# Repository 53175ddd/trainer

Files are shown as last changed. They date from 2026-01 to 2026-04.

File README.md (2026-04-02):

# trainer でできること

Arduino を使ったプログラミング学習用の教材です．段階を踏んで様々なことを学ぶことができるよう開発を進めています．

## 本リポジトリで管理されているもの

- 専用の開発ボード
  - `./boards/`
- 各種サンプルコード
  - `./samples/`
- 各種ドキュメント（Web ページとして公開）
  - `./docs/`
- 関連リンク

## ハードウェア

実習用に，秋月電子で購入できる RP2040 搭載のマイコンボード「AE-RP2040」を使用するハードウェア「trainer-pico」を用意しています．

基板イメージ：<https://kicanvas.org/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>

// 基板が出来上がったら Booth の購入リンクを追加する

## ドキュメント

// ある程度開発が進んでから整備する  
// `./docs/` 以下に配置し GitHub Pages で公開の上，そのリンクをここに貼る

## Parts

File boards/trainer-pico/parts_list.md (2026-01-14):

# trainer-pico 部品表

| 部品番号 | 部品名 | 型番等 | リンク | 備考 |
|:----|:----|:----|:----|:----|
| C1 | コンデンサ | Rubycon 50PX100MEFC8X11.5 | [117905](<https://akizukidenshi.com/catalog/g/g117905/>) | 100uF 50V |
| C2 | コンデンサ | Rubycon 50PX100MEFC8X11.5 | [117905](<https://akizukidenshi.com/catalog/g/g117905/>) | C1 と同じ |
| C3 | コンデンサ | muRata GCM21BR71H224KA37L | [C161262](<https://www.lcsc.com/product-detail/C161262.html>) | PCBA<sup>[1]</sup> |
| C4 | コンデンサ | muRata GCM21BR71H224KA37L | [C161262](<https://www.lcsc.com/product-detail/C161262.html>) | PCBA |
| C5 | コンデンサ | muRata GRM188R71H104KA93D | [C77055](<https://www.lcsc.com/product-detail/C77055.html>) | PCBA |
| C6 | コンデンサ | muRata GRM188R71H104KA93D | [C77055](<https://www.lcsc.com/product-detail/C77055.html>) | PCBA |
| C7 | コンデンサ | Rubycon 25MH747MEFC6.3X7 | [110596](<https://akizukidenshi.com/catalog/g/g110596/>) | 47uF 25V |
| C8 | コンデンサ | Rubycon 25MH747MEFC6.3X7 | [110596](<https://akizukidenshi.com/catalog/g/g110596/>) | C2 と同じ |
| C9 | コンデンサ | muRata GRM31CR61H106KA12L | [C77092](<https://www.lcsc.com/product-detail/C77092.html>) | PCBA |
| D1 | ダイオード | DIODES 1N4148W-7-F | [C83528](<https://www.lcsc.com/product-detail/C83528.html>) | PCBA |
| D2 | ダイオード | DIODES 1N4148W-7-F | [C83528](<https://www.lcsc.com/product-detail/C83528.html>) | D1 と同じ |
| D3 | ダイオード | DIODES 1N4148W-7-F | [C83528](<https://www.lcsc.com/product-detail/C83528.html>) | D1 と同じ |
| J1 | ピンヘッダ | PH-1x40SG | [100167](<https://akizukidenshi.com/catalog/g/g100167/>) | 必要な分だけ折り取って使用 |
| J2 | ピンヘッダ | PH-1x40SG | [100167](<https://akizukidenshi.com/catalog/g/g100167/>) | 必要な分だけ折り取って使用 |
| J3 | ピンヘッダ | PH-1x40SG | [100167](<https://akizukidenshi.com/catalog/g/g100167/>) | 必要な分だけ折り取って使用 |
| J4 | ピンヘッダ | PH-1x40SG | [100167](<https://akizukidenshi.com/catalog/g/g100167/>) | 必要な分だけ折り取って使用 |
| J5 | ピンヘッダ | PH-1x40SG | [100167](<https://akizukidenshi.com/catalog/g/g100167/>) | 必要な分だけ折り取って使用 |
| J6 | ピンソケット | FHU-1x42SG | [105779](<https://akizukidenshi.com/catalog/g/g105779/>) | 必要な分だけ折り取って使用 |
| J7 | ピンソケット | FHU-1x42SG | [105779](<https://akizukidenshi.com/catalog/g/g105779/>) | 必要な分だけ折り取って使用 |
| J8 | ピンソケット | FHU-1x42SG | [105779](<https://akizukidenshi.com/catalog/g/g105779/>) | 必要な分だけ折り取って使用 |
| J9 | ピンソケット | FHU-1x42SG | [105779](<https://akizukidenshi.com/catalog/g/g105779/>) | 必要な分だけ折り取って使用 |
| J10 | ピンソケット | FHU-1x42SG | [105779](<https://akizukidenshi.com/catalog/g/g105779/>) | 必要な分だけ折り取って使用 |
| J11 | ピンヘッダ | PH-1x40SG | [100167](<https://akizukidenshi.com/catalog/g/g100167/>) | 必要な分だけ折り取って使用 |
| J12 | ピンソケット | FHU-1x42SG | [105779](<https://akizukidenshi.com/catalog/g/g105779/>) | 必要な分だけ折り取って使用 |
| J13 | ピンソケット | FHU-1x42SG | [105779](<https://akizukidenshi.com/catalog/g/g105779/>) | 必要な分だけ折り取って使用 |
| J14 | ピンヘッダ | PH-1x40SG | [100167](<https://akizukidenshi.com/catalog/g/g100167/>) | 必要な分だけ折り取って使用 |
| J15 | DC ジャック | MJ-179PH | [106568](<https://akizukidenshi.com/catalog/g/g106568/>) |  |
| J16 | ピンヘッダ | PH-1x40SG | [100167](<https://akizukidenshi.com/catalog/g/g100167/>) | 必要な分だけ折り取って使用 |
| J17 | ピンヘッダ | PH-1x40SG | [100167](<https://akizukidenshi.com/catalog/g/g100167/>) | 必要な分だけ折り取って使用 |
| J18 | ピンヘッダ | PH-1x40SG | [100167](<https://akizukidenshi.com/catalog/g/g100167/>) | 必要な分だけ折り取って使用 |
| J19 | ピンヘッダ | PH-1x40SG | [100167](<https://akizukidenshi.com/catalog/g/g100167/>) | 必要な分だけ折り取って使用 |
| J20 | ピンヘッダ | PH-1x40SG | [100167](<https://akizukidenshi.com/catalog/g/g100167/>) | 必要な分だけ折り取って使用 |
| R1 | 抵抗 | YAGEO RC0603FR-0710KL | [C98220](<https://www.lcsc.com/product-detail/C98220.html>) | PCBA |
| R1 | 抵抗 | YAGEO RC0603FR-0710KL | [C98220](<https://www.lcsc.com/product-detail/C98220.html>) | R1 と同じ |
| U1 | マイコンボード | AE-RP2040 | [117542](<https://akizukidenshi.com/catalog/g/g117542/>) |  |
| U2 | 電源レギュレータ | ST L7805ABD2T-TR | [C86206](<https://www.lcsc.com/product-detail/C86206.html>) | PCBA |
| U3 | 電源レギュレータ | ST L7809ABD2T-TR | [C262905](<https://www.lcsc.com/product-detail/C262905.html>) | PCBA |

[1] : PCBA での実装対応

# 追加で必要な部品

- [MPS-04-0](<https://akizukidenshi.com/catalog/g/g110089/>)
  - 基板の四隅の穴につけるスペーサ
- [LCF-5](<https://akizukidenshi.com/catalog/g/g112322/>)
  - ユニバーサル基板を連結するスペーサ
- [ユニバーサル基板（C タイプ）](<https://akizukidenshi.com/catalog/g/g100517/>)
  - オリジナルの回路を乗せるユニバーサル基板

マイコンボード（AE-RP2040）を直接実装せず，ソケットを使用したい場合は以下の部品を使用してください．

- [6604S-40](<https://akizukidenshi.com/catalog/g/g101591/>)

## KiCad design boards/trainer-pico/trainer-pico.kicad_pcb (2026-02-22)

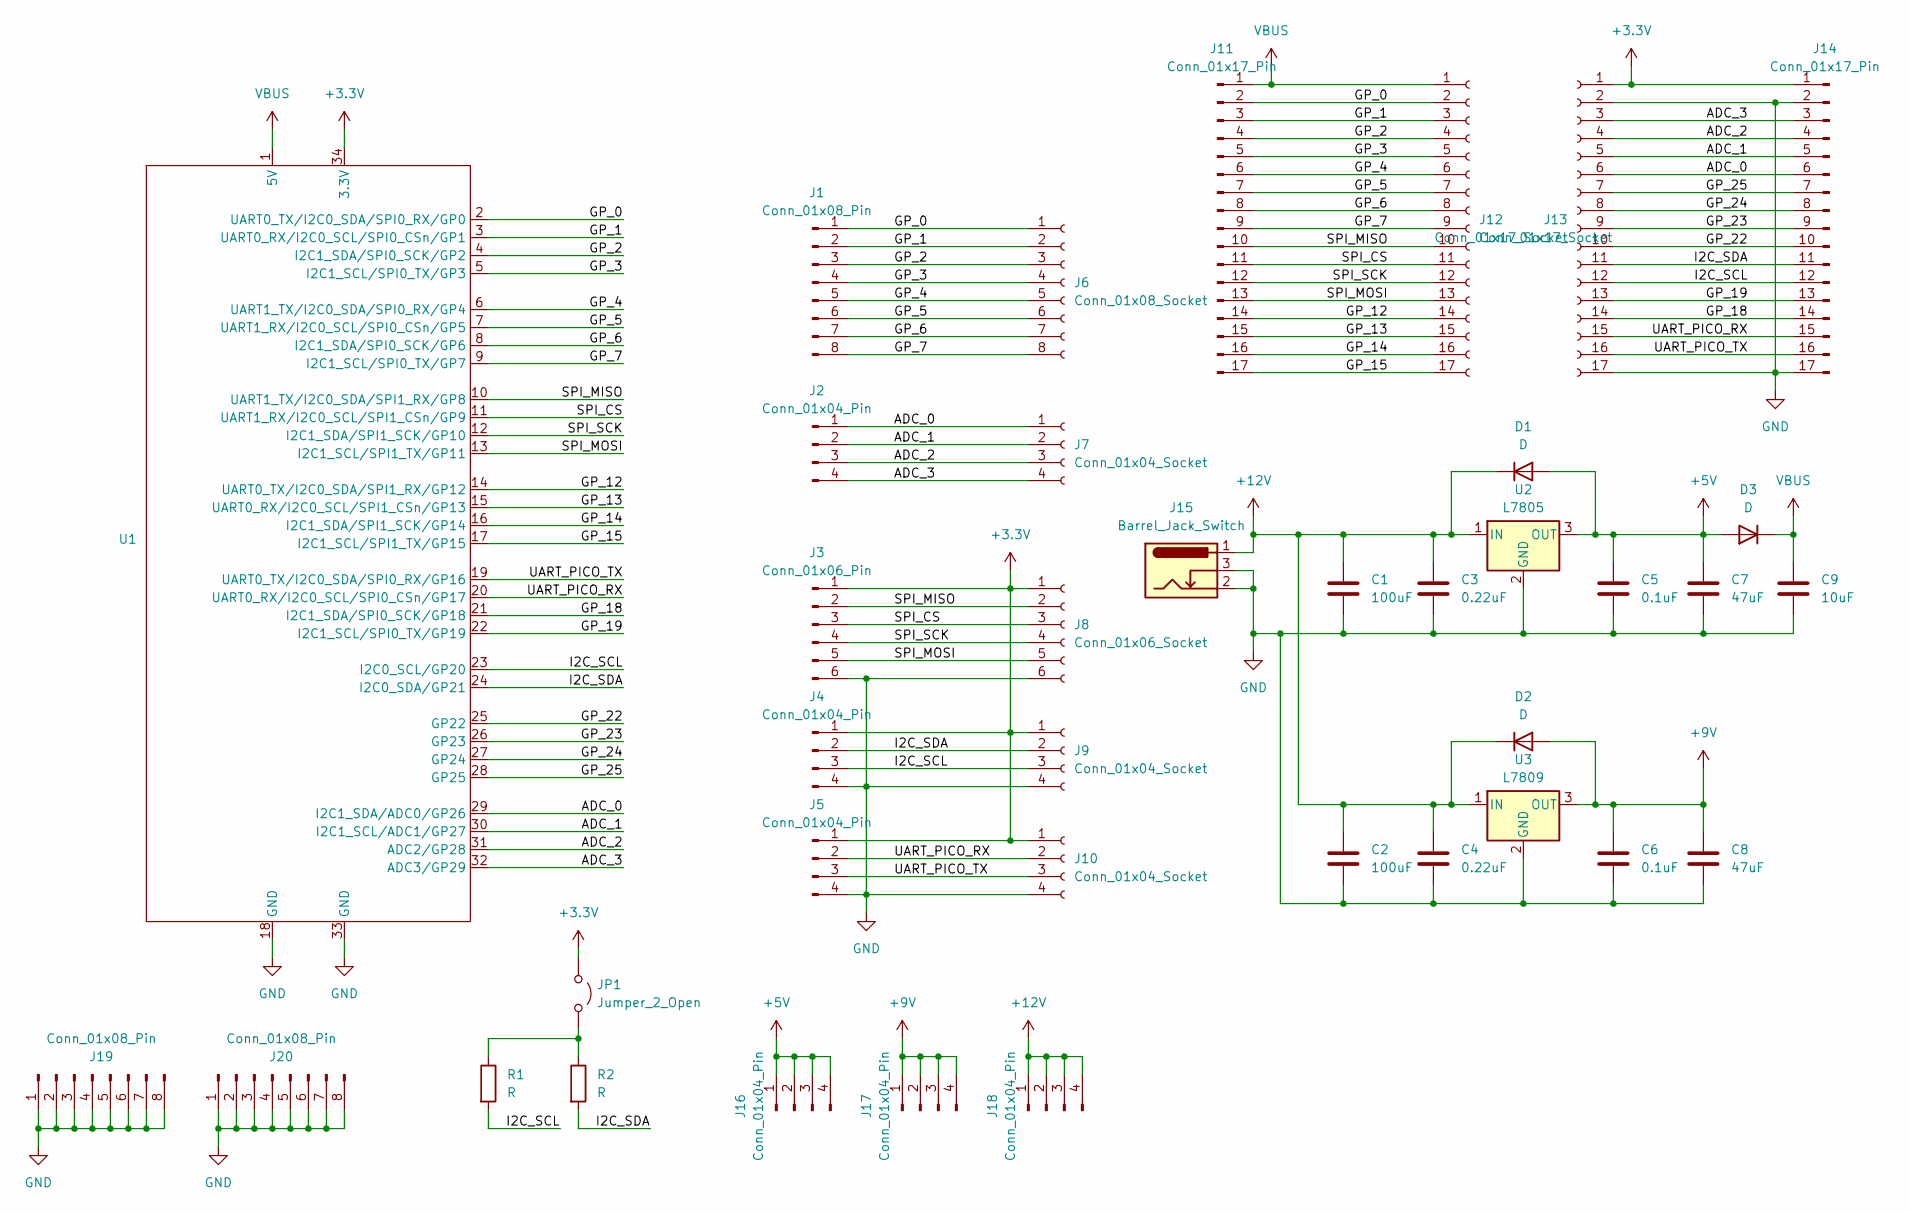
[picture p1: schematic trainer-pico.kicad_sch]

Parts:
C1, C2: 100uF; CP_Radial_D8.0mm_P3.50mm
C3, C4: 0.22uF; C_0805_2012Metric; LCSC C161262
C5, C6: 0.1uF; C_0603_1608Metric; LCSC C77055
C7, C8: 47uF; CP_Radial_D6.3mm_P2.50mm
C9: 10uF; C_1206_3216Metric; LCSC C77092
D1, D2, D3: D; D_SOD-123F; LCSC C83528
J1: Conn_01x08_Pin; PinHeader_1x08_P2.54mm_Vertical
J2, J4, J5: Conn_01x04_Pin; PinHeader_1x04_P2.54mm_Vertical
J3: Conn_01x06_Pin; PinHeader_1x06_P2.54mm_Vertical
J6: Conn_01x08_Socket; PinSocket_1x08_P2.54mm_Vertical
J7, J9, J10: Conn_01x04_Socket; PinSocket_1x04_P2.54mm_Vertical
J8: Conn_01x06_Socket; PinSocket_1x06_P2.54mm_Vertical
J11, J14: Conn_01x17_Pin; PinHeader_1x17_P2.54mm_Vertical
J12, J13: Conn_01x17_Socket; PinSocket_1x17_P2.54mm_Vertical
J15: Barrel_Jack_Switch; BarrelJack_Horizontal
J16, J17, J18: Conn_01x04_Pin; PinSocket_1x04_P2.54mm_Vertical
J19, J20: Conn_01x08_Pin; PinSocket_1x08_P2.54mm_Vertical
JP1: Jumper_2_Open; SolderJumper-2_P1.3mm_Open_RoundedPad1.0x1.5mm
R1, R2: R; R_0603_1608Metric; LCSC C98220
U1: AE-RP2040
U2: L7805; TO-263-2; LCSC C86206
U3: L7809; TO-263-2; LCSC C262905

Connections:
+3.3V: J3.1, J4.1, J5.1, J8.1, J9.1, J10.1, J13.1, J14.1, JP1.1 (A), U1.34 (3.3V)
+5V: C5.1, C7.1, D1.2 (A), D3.2 (A), J16.1, J16.2, J16.3, J16.4, U2.3 (OUT)
+9V: C6.1, C8.1, D2.2 (A), J17.1, J17.2, J17.3, J17.4, U3.3 (OUT)
+12V: C1.1, C2.1, C3.1, C4.1, D1.1 (K), D2.1 (K), J15.1, J18.1, J18.2, J18.3, J18.4, U2.1 (IN), U3.1 (IN)
/ADC_0: J2.1, J7.1, J13.6, J14.6, U1.29 (I2C1_SDA/ADC0/GP26)
/ADC_1: J2.2, J7.2, J13.5, J14.5, U1.30 (I2C1_SCL/ADC1/GP27)
/ADC_2: J2.3, J7.3, J13.4, J14.4, U1.31 (ADC2/GP28)
/ADC_3: J2.4, J7.4, J13.3, J14.3, U1.32 (ADC3/GP29)
/GP_0: J1.1, J6.1, J11.2, J12.2, U1.2 (UART0_TX/I2C0_SDA/SPI0_RX/GP0)
/GP_1: J1.2, J6.2, J11.3, J12.3, U1.3 (UART0_RX/I2C0_SCL/SPI0_CSn/GP1)
/GP_2: J1.3, J6.3, J11.4, J12.4, U1.4 (I2C1_SDA/SPI0_SCK/GP2)
/GP_3: J1.4, J6.4, J11.5, J12.5, U1.5 (I2C1_SCL/SPI0_TX/GP3)
/GP_4: J1.5, J6.5, J11.6, J12.6, U1.6 (UART1_TX/I2C0_SDA/SPI0_RX/GP4)
/GP_5: J1.6, J6.6, J11.7, J12.7, U1.7 (UART1_RX/I2C0_SCL/SPI0_CSn/GP5)
/GP_6: J1.7, J6.7, J11.8, J12.8, U1.8 (I2C1_SDA/SPI0_SCK/GP6)
/GP_7: J1.8, J6.8, J11.9, J12.9, U1.9 (I2C1_SCL/SPI0_TX/GP7)
/GP_12: J11.14, J12.14, U1.14 (UART0_TX/I2C0_SDA/SPI1_RX/GP12)
/GP_13: J11.15, J12.15, U1.15 (UART0_RX/I2C0_SCL/SPI1_CSn/GP13)
/GP_14: J11.16, J12.16, U1.16 (I2C1_SDA/SPI1_SCK/GP14)
/GP_15: J11.17, J12.17, U1.17 (I2C1_SCL/SPI1_TX/GP15)
/GP_18: J13.14, J14.14, U1.21 (I2C1_SDA/SPI0_SCK/GP18)
/GP_19: J13.13, J14.13, U1.22 (I2C1_SCL/SPI0_TX/GP19)
/GP_22: J13.10, J14.10, U1.25 (GP22)
/GP_23: J13.9, J14.9, U1.26 (GP23)
/GP_24: J13.8, J14.8, U1.27 (GP24)
/GP_25: J13.7, J14.7, U1.28 (GP25)
/I2C_SCL: J4.3, J9.3, J13.12, J14.12, R1.2, U1.23 (I2C0_SCL/GP20)
/I2C_SDA: J4.2, J9.2, J13.11, J14.11, R2.2, U1.24 (I2C0_SDA/GP21)
/SPI_CS: J3.3, J8.3, J11.11, J12.11, U1.11 (UART1_RX/I2C0_SCL/SPI1_CSn/GP9)
/SPI_MISO: J3.2, J8.2, J11.10, J12.10, U1.10 (UART1_TX/I2C0_SDA/SPI1_RX/GP8)
/SPI_MOSI: J3.5, J8.5, J11.13, J12.13, U1.13 (I2C1_SCL/SPI1_TX/GP11)
/SPI_SCK: J3.4, J8.4, J11.12, J12.12, U1.12 (I2C1_SDA/SPI1_SCK/GP10)
/UART_PICO_RX: J5.2, J10.2, J13.15, J14.15, U1.20 (UART0_RX/I2C0_SCL/SPI0_CSn/GP17)
/UART_PICO_TX: J5.3, J10.3, J13.16, J14.16, U1.19 (UART0_TX/I2C0_SDA/SPI0_RX/GP16)
GND: C1.2, C2.2, C3.2, C4.2, C5.2, C6.2, C7.2, C8.2, C9.2, J3.6, J4.4, J5.4, J8.6, J9.4, J10.4, J13.2, J13.17, J14.2, J14.17, J15.2, J15.3, J19.1, J19.2, J19.3, J19.4, J19.5, J19.6, J19.7, J19.8, J20.1, J20.2, J20.3, J20.4, J20.5, J20.6, J20.7, J20.8, U1.18 (GND), U1.33 (GND), U2.2 (GND), U3.2 (GND)
unnamed: JP1.2 (B), R1.1, R2.1
VBUS: C9.1, D3.1 (K), J11.1, J12.1, U1.1 (5V)

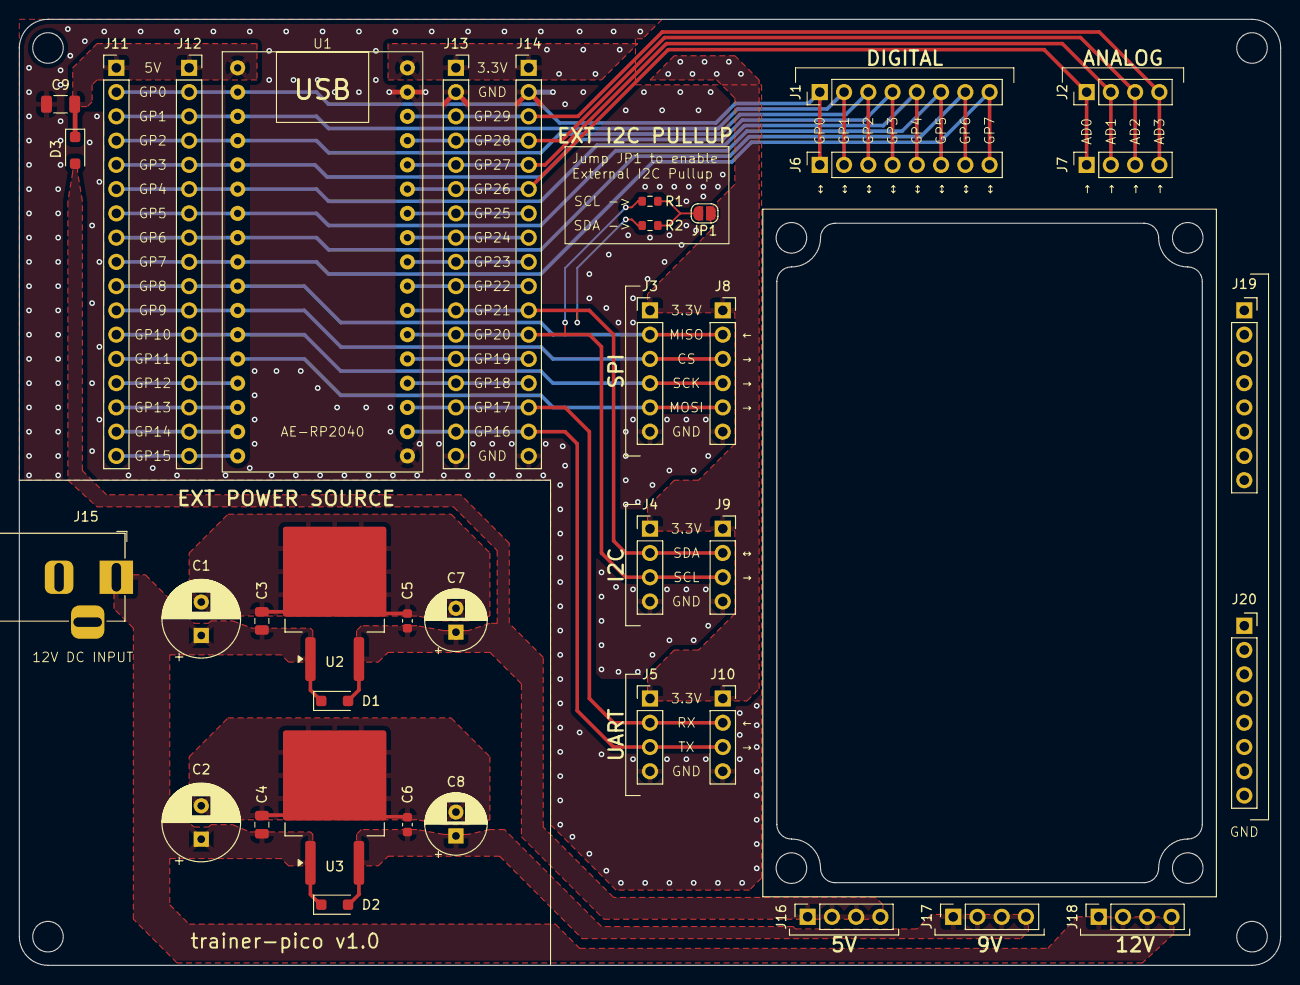
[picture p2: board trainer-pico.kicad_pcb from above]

Board: 2 copper layers, 132.1 x 99.1 mm, 38 parts (0 on the bottom side), 37 nets.

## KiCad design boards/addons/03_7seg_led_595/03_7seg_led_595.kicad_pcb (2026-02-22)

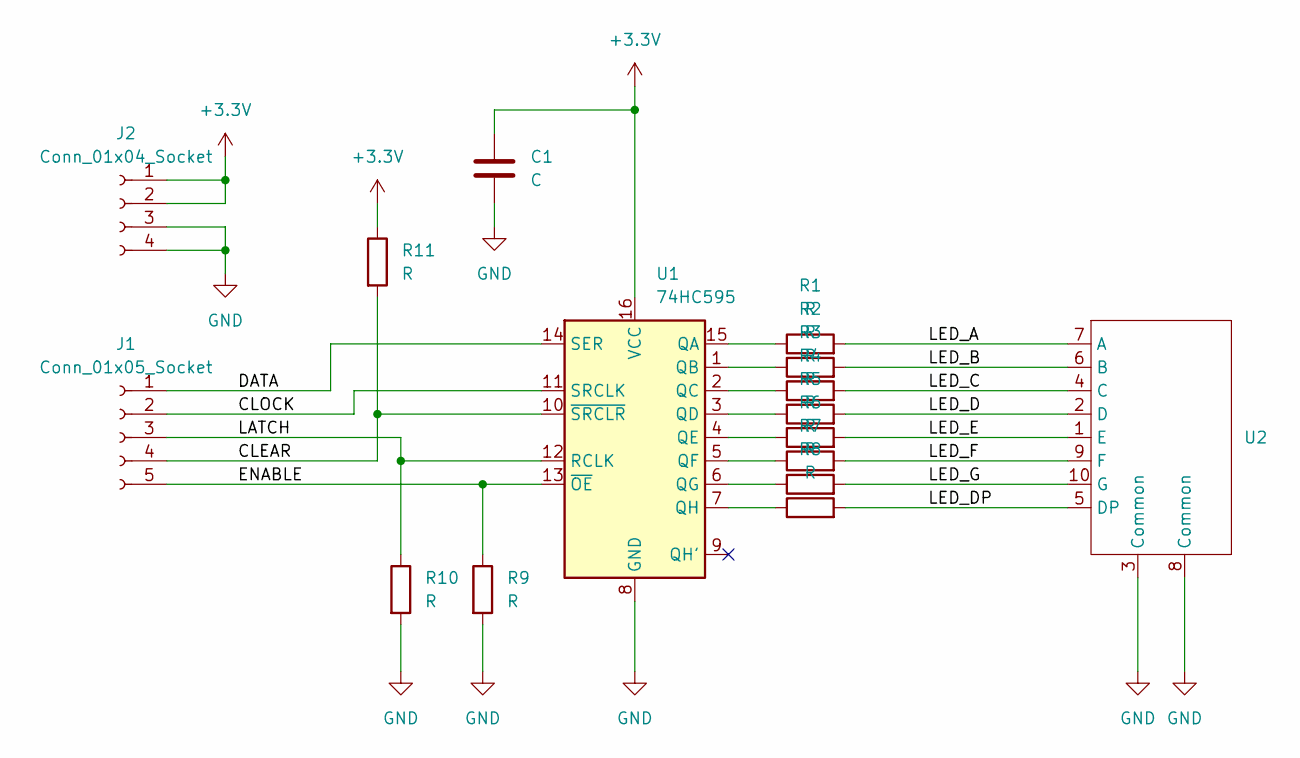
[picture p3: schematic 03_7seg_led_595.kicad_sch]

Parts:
C1: C; C_Disc_D6.0mm_W2.5mm_P5.00mm
J1: Conn_01x05_Socket; PinSocket_1x05_P2.54mm_Vertical
J2: Conn_01x04_Socket; PinSocket_1x04_P2.54mm_Vertical
R1, R2, R3, R4, R5, R6, R7, R8, R9, R10, R11: R; R_Axial_DIN0207_L6.3mm_D2.5mm_P10.16mm_Horizontal
U1: 74HC595; DIP-16_W7.62mm
U2: OSL10561

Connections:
+3.3V: C1.1, J2.1, J2.2, R11.1, U1.16 (VCC)
/CLEAR: J1.4, R11.2, U1.10 (~SRCLR)
/CLOCK: J1.2, U1.11 (SRCLK)
/DATA: J1.1, U1.14 (SER)
/ENABLE: J1.5, R9.1, U1.13 (~OE)
/LATCH: J1.3, R10.1, U1.12 (RCLK)
/LED_A: R1.2, U2.7 (A)
/LED_B: R2.2, U2.6 (B)
/LED_C: R3.2, U2.4 (C)
/LED_D: R4.2, U2.2 (D)
/LED_DP: R8.2, U2.5 (DP)
/LED_E: R5.2, U2.1 (E)
/LED_F: R6.2, U2.9 (F)
/LED_G: R7.2, U2.10 (G)
GND: C1.2, J2.3, J2.4, R9.2, R10.2, U1.8 (GND), U2.3 (Common), U2.8 (Common)
unnamed: R1.1, U1.15 (QA)
unnamed: R2.1, U1.1 (QB)
unnamed: R3.1, U1.2 (QC)
unnamed: R4.1, U1.3 (QD)
unnamed: R5.1, U1.4 (QE)
unnamed: R6.1, U1.5 (QF)
unnamed: R7.1, U1.6 (QG)
unnamed: R8.1, U1.7 (QH)

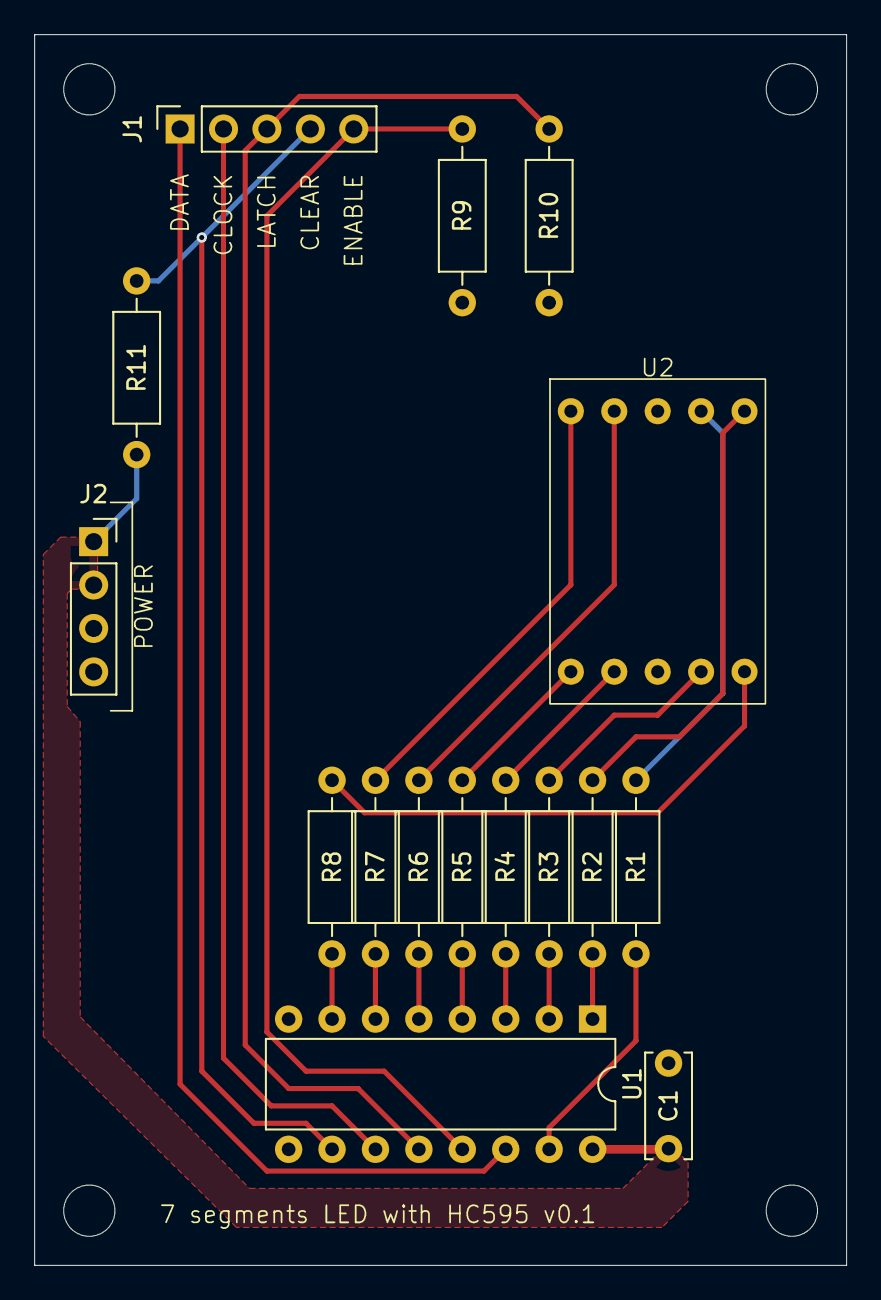
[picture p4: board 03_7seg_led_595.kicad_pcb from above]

Board: 2 copper layers, 47.5 x 72.0 mm, 16 parts (0 on the bottom side), 23 nets.

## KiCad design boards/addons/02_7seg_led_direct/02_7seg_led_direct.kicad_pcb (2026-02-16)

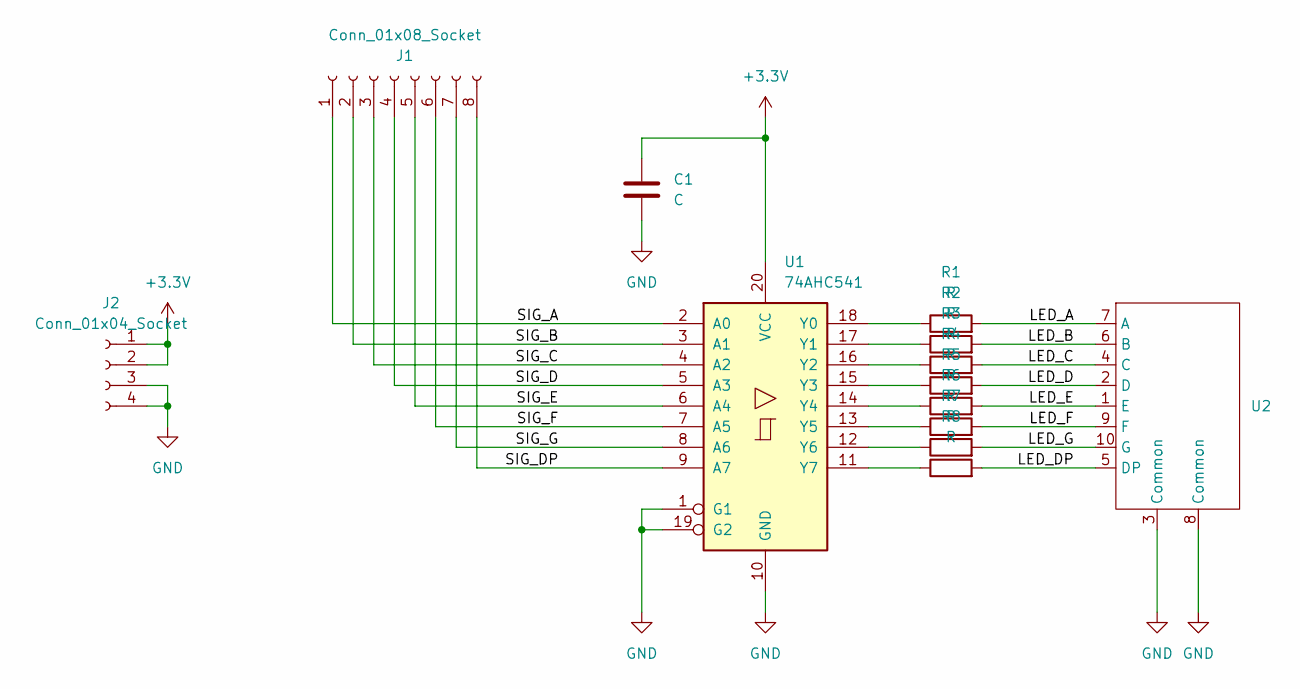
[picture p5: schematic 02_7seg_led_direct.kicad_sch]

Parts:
C1: C; C_Disc_D6.0mm_W2.5mm_P5.00mm
J1: Conn_01x08_Socket; PinSocket_1x08_P2.54mm_Vertical
J2: Conn_01x04_Socket; PinSocket_1x04_P2.54mm_Vertical
R1, R2, R3, R4, R5, R6, R7, R8: R; R_Axial_DIN0207_L6.3mm_D2.5mm_P10.16mm_Horizontal
U1: 74AHC541; DIP-20_W7.62mm
U2: OSL10561

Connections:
+3.3V: C1.1, J2.1, J2.2, U1.20 (VCC)
/LED_A: R1.2, U2.7 (A)
/LED_B: R2.2, U2.6 (B)
/LED_C: R3.2, U2.4 (C)
/LED_D: R4.2, U2.2 (D)
/LED_DP: R8.2, U2.5 (DP)
/LED_E: R5.2, U2.1 (E)
/LED_F: R6.2, U2.9 (F)
/LED_G: R7.2, U2.10 (G)
/SIG_A: J1.1, U1.2 (A0)
/SIG_B: J1.2, U1.3 (A1)
/SIG_C: J1.3, U1.4 (A2)
/SIG_D: J1.4, U1.5 (A3)
/SIG_DP: J1.8, U1.9 (A7)
/SIG_E: J1.5, U1.6 (A4)
/SIG_F: J1.6, U1.7 (A5)
/SIG_G: J1.7, U1.8 (A6)
GND: C1.2, J2.3, J2.4, U1.1 (G1), U1.10 (GND), U1.19 (G2), U2.3 (Common), U2.8 (Common)
unnamed: R1.1, U1.18 (Y0)
unnamed: R2.1, U1.17 (Y1)
unnamed: R3.1, U1.16 (Y2)
unnamed: R4.1, U1.15 (Y3)
unnamed: R5.1, U1.14 (Y4)
unnamed: R6.1, U1.13 (Y5)
unnamed: R7.1, U1.12 (Y6)
unnamed: R8.1, U1.11 (Y7)

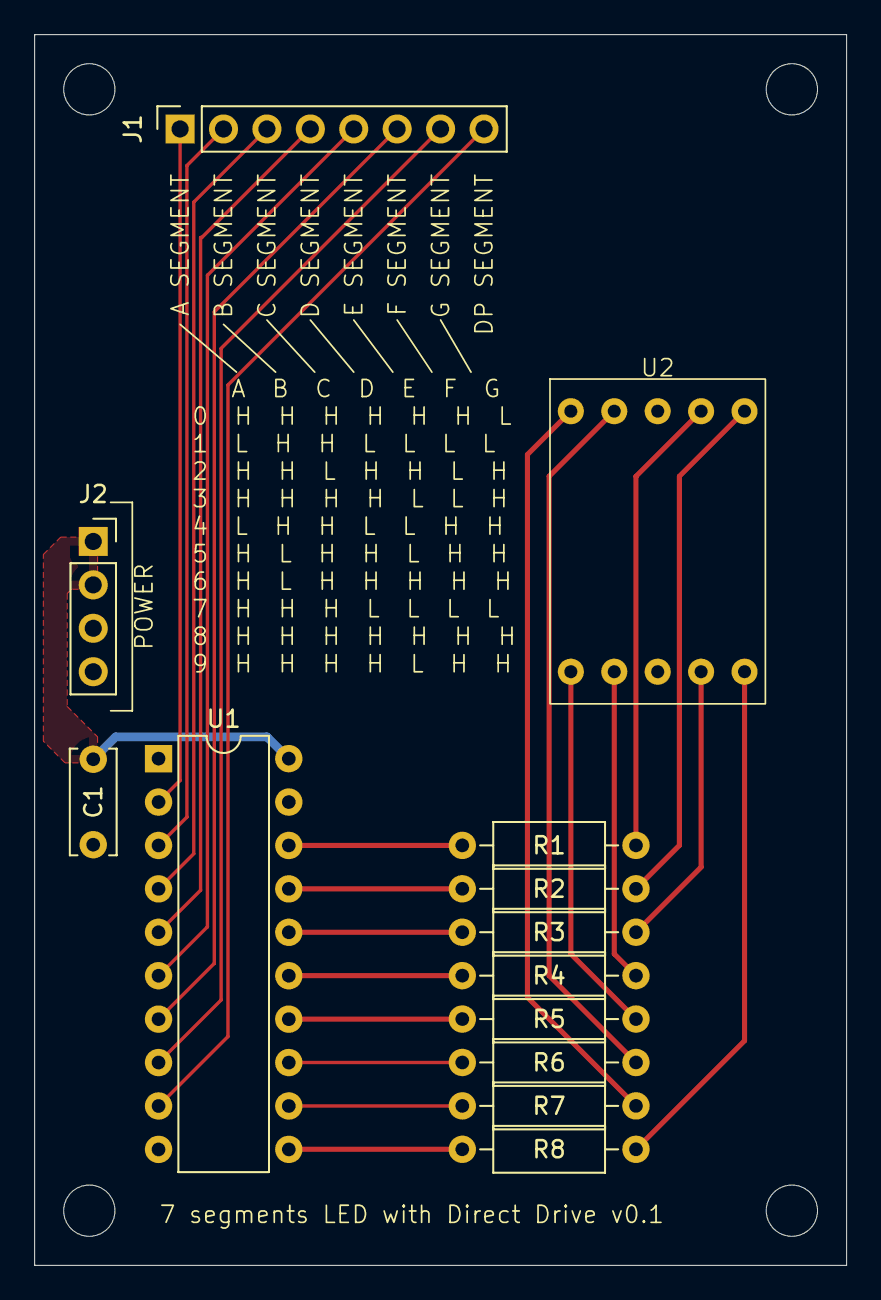
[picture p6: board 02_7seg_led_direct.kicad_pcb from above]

Board: 2 copper layers, 47.5 x 72.0 mm, 13 parts (0 on the bottom side), 26 nets.

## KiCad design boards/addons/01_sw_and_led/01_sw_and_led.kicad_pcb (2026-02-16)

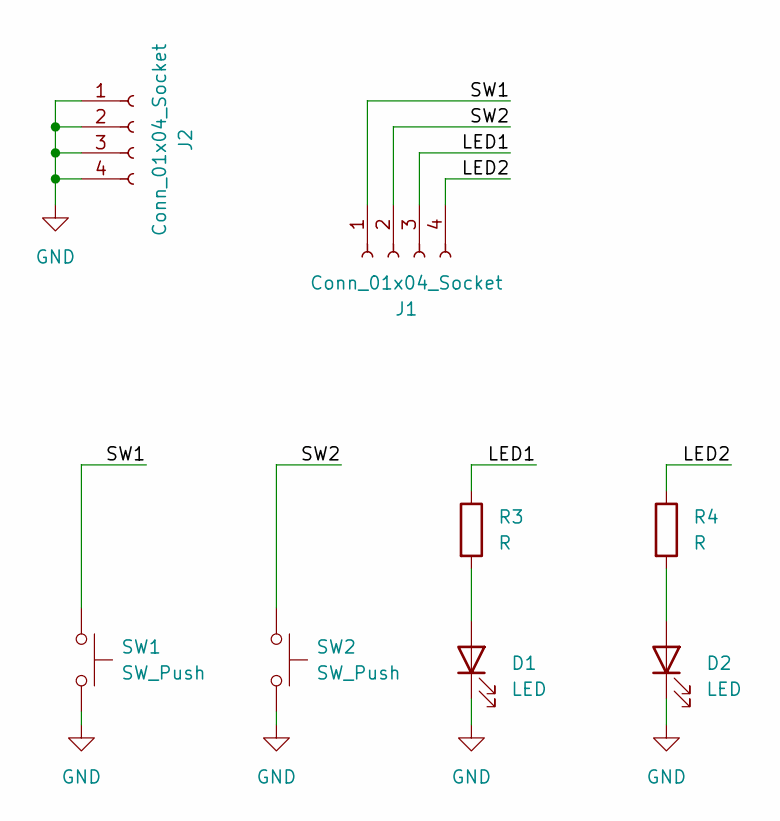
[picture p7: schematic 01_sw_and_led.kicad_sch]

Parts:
D1, D2: LED; LED_D5.0mm
J1, J2: Conn_01x04_Socket; PinSocket_1x04_P2.54mm_Vertical
R3, R4: R; R_Axial_DIN0207_L6.3mm_D2.5mm_P10.16mm_Horizontal
SW1, SW2: SW_Push; SW_PUSH-12mm

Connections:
/LED1: J1.3, R3.1
/LED2: J1.4, R4.1
/SW1: J1.1, SW1.1
/SW2: J1.2, SW2.1
GND: D1.1 (K), D2.1 (K), J2.1, J2.2, J2.3, J2.4, SW1.2, SW2.2
unnamed: D1.2 (A), R3.2
unnamed: D2.2 (A), R4.2

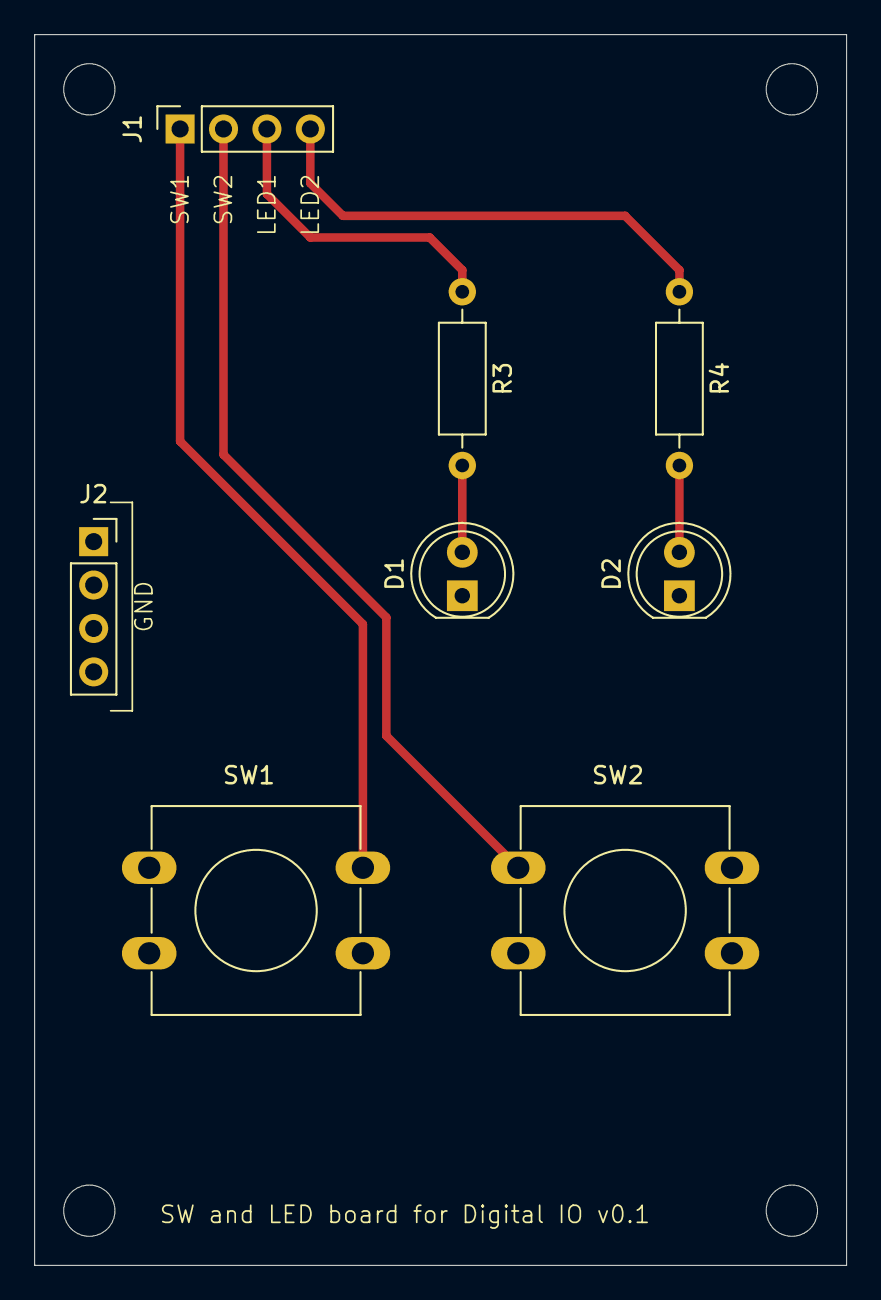
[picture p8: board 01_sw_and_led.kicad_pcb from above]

Board: 2 copper layers, 47.5 x 72.0 mm, 8 parts (0 on the bottom side), 7 nets.

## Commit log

2026-01-02 create kicad project file
    [trainer-nano.kicad_pcb, trainer-nano.kicad_sch, trainer-pico.kicad_pcb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]
2026-01-02 create footprint and symbol of AE-RP2040
2026-01-10 暫定回路
    [trainer-pico.kicad_sch]
2026-01-11 部品配置を概ね fix
    [trainer-pico.kicad_pcb]
2026-01-11 アノテーションの修正
    [trainer-pico.kicad_pcb, trainer-pico.kicad_sch]
2026-01-11 ベタを調整
    [trainer-pico.kicad_pcb]
2026-01-12 配線の取り回しを改善
    [trainer-pico.kicad_pcb, trainer-pico.kicad_sch]
2026-01-12 I2C の外部プルアップ用の回路を追加
    [trainer-pico.kicad_pcb, trainer-pico.kicad_sch]
2026-01-13 電源パターンを調整
    [trainer-pico.kicad_pcb]
2026-01-13 シルクの刻印をいい感じにした
    [trainer-pico.kicad_pcb]
2026-01-13 Pico の両側にピンソケット・ピンヘッダを追加
    [trainer-pico.kicad_pcb, trainer-pico.kicad_sch]
2026-01-14 Pico の両側に IO 番号の刻印を追加
    [trainer-pico.kicad_pcb]
2026-01-14 配線を微修正
    [trainer-pico.kicad_pcb]
2026-01-14 外部電源追加
    [trainer-pico.kicad_pcb, trainer-pico.kicad_sch]
2026-01-14 trainer-nano を削除
    trainer-nano 作るのやめて pico 一本で進めることにした
    [trainer-nano.kicad_pcb, trainer-nano.kicad_sch]
2026-01-14 PCBA 用のパーツ番号を追加
    [trainer-pico.kicad_sch]
2026-01-14 配線を修正
    [trainer-pico.kicad_pcb]
2026-01-14 シルクの刻印を追加
    [trainer-pico.kicad_pcb]
2026-01-15 電源プレーンの修正と via 打ち職人
    [trainer-pico.kicad_pcb]
2026-01-15 ズレてたシルクを戻した
    [trainer-pico.kicad_pcb]
2026-01-15 additional via 打ち職人
    [trainer-pico.kicad_pcb]
2026-01-15 シルクのバージョンを改番
    [trainer-pico.kicad_pcb]
2026-01-17 ベタが気に食わなかったので修正
    [trainer-pico.kicad_pcb, trainer-pico.kicad_sch]
2026-01-18 L チカ基板の pj 作成
    [01_sw_and_led.kicad_pcb, 01_sw_and_led.kicad_sch]
2026-01-18 回路図書いて FP 割り当て
    [01_sw_and_led.kicad_sch]
2026-01-18 大雑把に部品配置
    [01_sw_and_led.kicad_pcb]
2026-01-18 電源と入出力のピンソケット追加
    [01_sw_and_led.kicad_sch]
2026-01-18 ピンソケット配置
    [01_sw_and_led.kicad_pcb]
2026-01-18 配置調整
    [01_sw_and_led.kicad_pcb]
2026-01-18 AW 引いた
    [01_sw_and_led.kicad_pcb]
2026-01-18 7 セグの pj
    [02_7seg_led_direct.kicad_pcb, 02_7seg_led_direct.kicad_sch]
2026-01-18 駆動回路だけ書いた
    [02_7seg_led_direct.kicad_sch]
2026-01-19 パターンが微妙にズレてたので直した
    [trainer-pico.kicad_pcb]
2026-01-19 ピンヘッダをピンソケットに変更
    [trainer-pico.kicad_pcb, trainer-pico.kicad_sch]
2026-02-15 もはや間違い探しレベルの微修正
    [trainer-pico.kicad_pcb]
2026-02-15 スイッチのプルアップ抵抗はなくしました
    [01_sw_and_led.kicad_pcb, 01_sw_and_led.kicad_sch]
2026-02-15 LED のシンボルとフットプリント
2026-02-15 かいろず
    [02_7seg_led_direct.kicad_sch]
2026-02-15 7seg その 1
    [02_7seg_led_direct.kicad_pcb]
2026-02-16 電源ベタの修正
    [trainer-pico.kicad_pcb]
2026-02-16 電源のシルク追加
    [trainer-pico.kicad_pcb]
2026-02-16 ゴミが残ってたので削除
    [trainer-pico.kicad_pcb]
2026-02-16 via の打ち直し
    [trainer-pico.kicad_pcb]
2026-02-16 電源ベタ修正
    [trainer-pico.kicad_pcb]
2026-02-16 シルク追加
    [trainer-pico.kicad_pcb]
2026-02-16 バージョンアップ
    [trainer-pico.kicad_pcb]
2026-02-16 ガーバー出力
    [trainer-pico.kicad_pcb]
2026-02-16 またもベタを微修正
    [trainer-pico.kicad_pcb]
2026-02-22 ベタの修正と via の打ち直し
    [trainer-pico.kicad_pcb]
2026-02-22 kicad pj
    [03_7seg_led_595.kicad_pcb, 03_7seg_led_595.kicad_sch]
2026-02-22 fp / sym 登録
2026-04-02 Add board image link for trainer-pico
    Added a link to the board image for the trainer-pico.
